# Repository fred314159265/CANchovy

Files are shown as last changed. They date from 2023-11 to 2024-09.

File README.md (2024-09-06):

# CANchovy USB-CAN Interface

This repository contains the design file for an isolated USB-CAN interface PCB. It is based upon the MKS CANable V2.0 and is compatible with the [CANable V2.0 firmware](https://github.com/normaldotcom/canable2-fw). It connects to the CAN bus via RJ45 connectors which can be configured with whatever pinout you require!

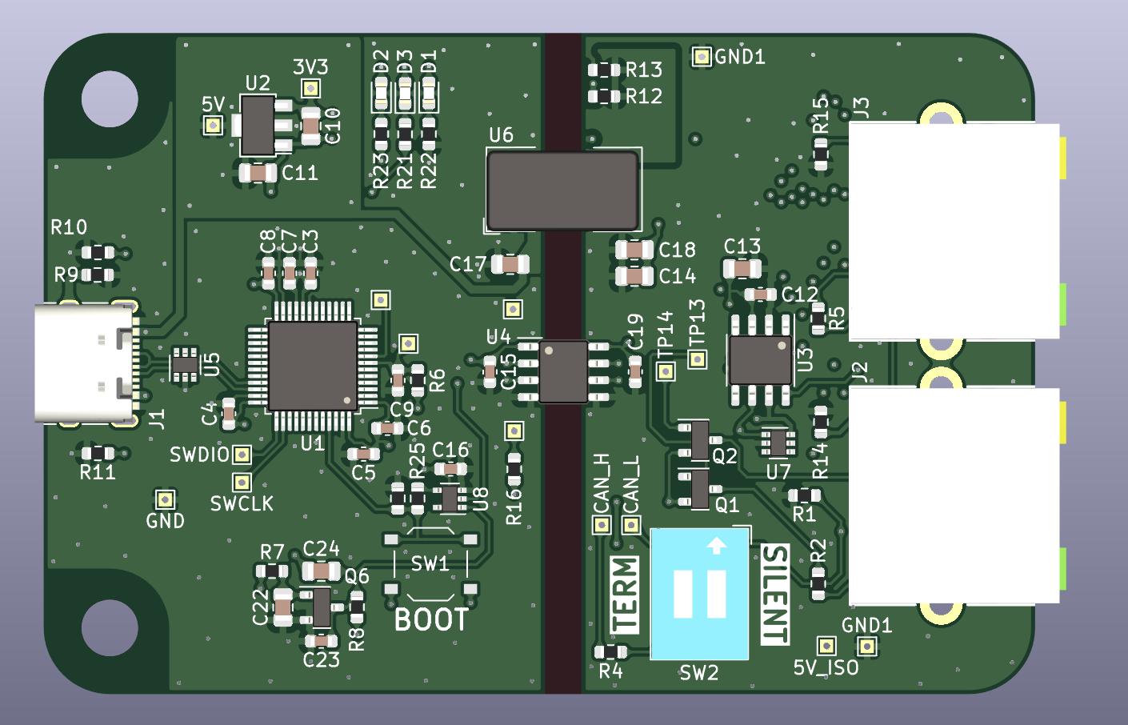
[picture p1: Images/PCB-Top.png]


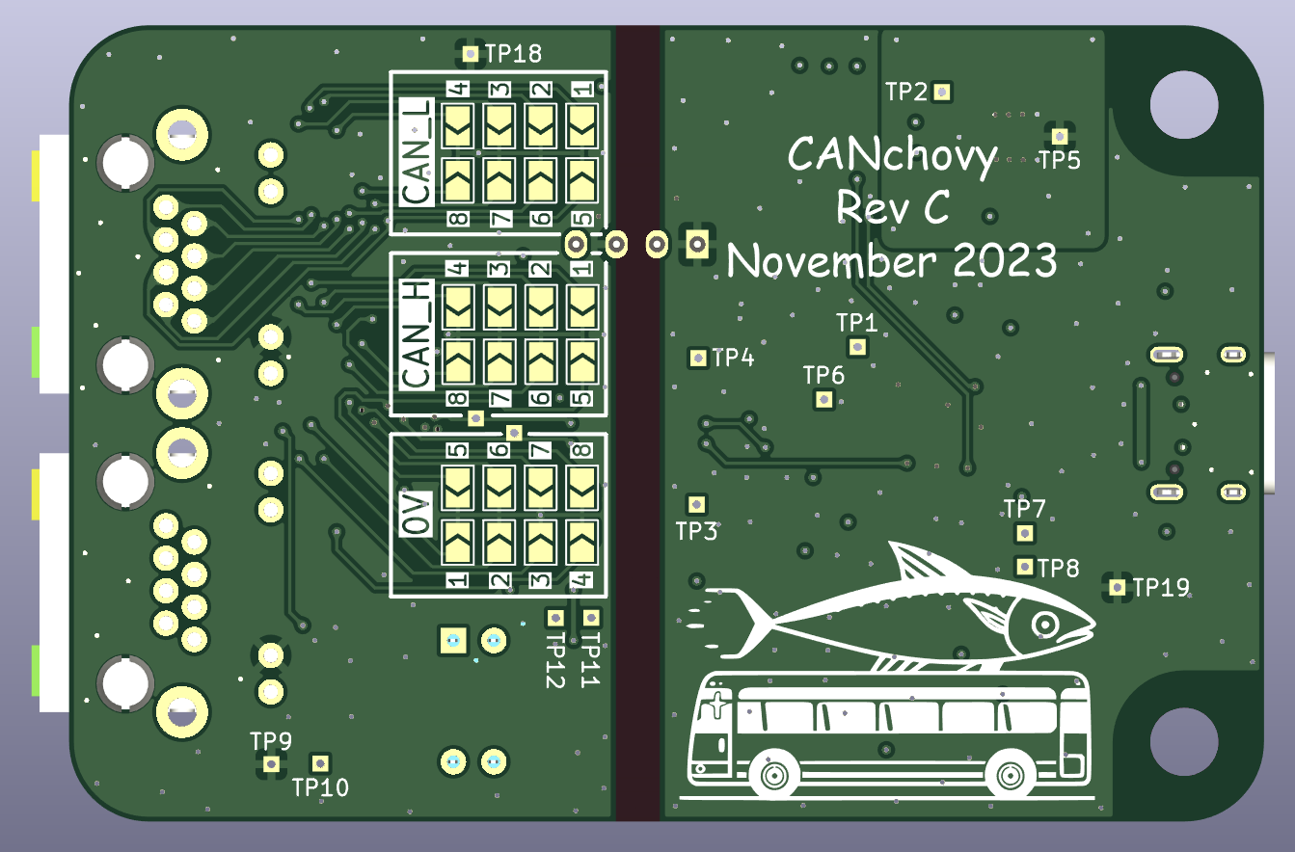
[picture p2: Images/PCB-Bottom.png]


## Features

* Firmware compatible with [CANable V2.0 firmware](https://github.com/normaldotcom/canable2-fw) - can be flashed & updated with the [CANable 2.0 web updater](https://canable.io/updater/canable2.html).
* RJ45 pinout configured via solder-able jumpers.
* Galvanic isolation between CAN port and USB.
* Two RJ45 connector in parallel allows for inserting inline on bus - all eight signal are passed through.
* DIP switch to enable or disable CAN termination.
* DIP switch to enable silent mode, preventing the CANchovy from transmitting on the bus in hardware.
* JLCPCB basic parts used where possible and all parts available for JLCPCB assembly service. Five CANchovies fully assembled with postage costs around $20 per CANchovy.
* 3D printed case design files.

# Status

Assembled CANchovies from JLCPCB of both revision A & B have been tested and work correctly. The only issues with these version were silkscreen issues.

Revision C has the silkscreen fixed and is ready to manufacture and use.

# Firmware

As the CANchovy is based upon the MKS CANable V2.0, it is compatible with firmware which is compatible with the MKS CANable V2.0.

There area couple of suitable firmware options - which firmware you will want to use really depends on your use case. 

## gs_usb

Using a firmware version which uses the gs_usb protocol will mostly be useful for SocketCAN on Linux, but [python-can](https://python-can.readthedocs.io/en/stable/interfaces/gs_usb.html) does support the gs_usb protocol on all platforms. (__Note:__ The Linux kernel only supports CAN FD with the gs_usb driver after version 5.18.)

* budgetcan_fw - [board_canablev2](https://github.com/ryedwards/budgetcan_fw/tree/main/Portable/board_canablev2) target - I have confirmed that FD CAN is working as of [`e8fb8efebdac22019dc7e73dfec773c6fd2ec5a8`](https://github.com/ryedwards/budgetcan-fw/commit/e8fb8efebdac22019dc7e73dfec773c6fd2ec5a8).
* candlelight build from [CANable 2.0 web updater](https://canable.io/updater/canable2.html) - I have not tested if FD CAN support is present, notes on canable website suggest FD support is not implemented in these candlelight FW builds (yet?).

## SLCAN

SLCAN is a protocol which operates over a serial port. Nearly all OS's have support for serial ports and so is very cross-platform. However, support for SLCAN is not very widespread.

You can also mount the serial port as a SocketCAN port on Linux (E.g. as described [here](https://elinux.org/Bringing_CAN_interface_up).), however, it does not support FD CAN at this time.

FD CAN is possible with the SLCAN firmware, but even fewer programs support FD with SLCAN (if any?). It may be a viable for custom applications where non-Linux is a requirement and Python is not an option.

* slcan with FD support build from [CANable 2.0 web updater](https://canable.io/updater/canable2.html) - [source repo](https://github.com/normaldotcom/canable2-fw).

# Configuring RJ45 Connections

As mentioned above, a feature of this board is that the RJ45's pinout is user configurable. By soldering one jumper for each of the three connections (0V, CAN_H, CAN_L) on the rear of the board, your custom CAN pinout over RJ45 can be supported!

Simply bridge one of the solder jumpers in each of the silkscreen boxes (labelled: 0V, CAN_H & CAN_L) to connect each signal to the corresponding pin number of the RJ45 connectors.

__⚠⚠⚠ Care must be taken to ensure no two signals are connected to the same RJ45 pin! ⚠⚠⚠__

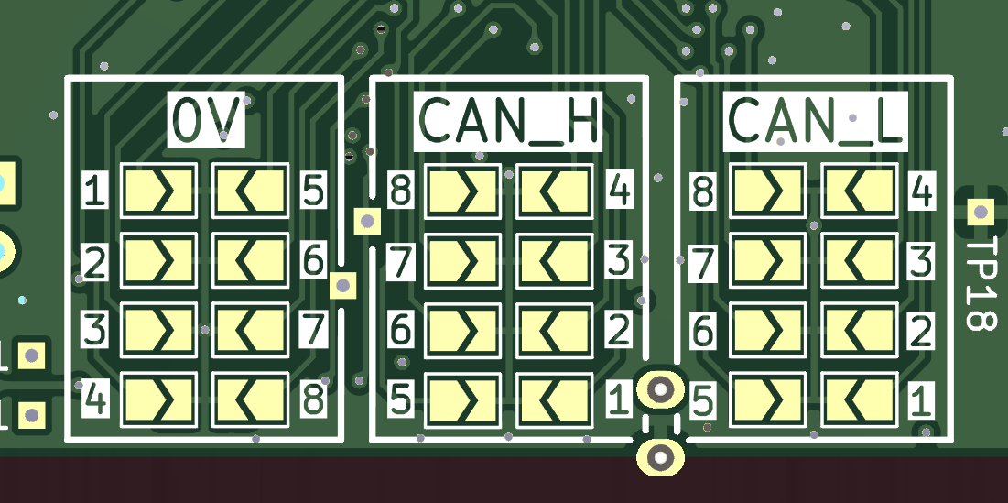
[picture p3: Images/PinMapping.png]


# Ordering

Gerbers, BOM, etc. can all be found in the [releases](https://github.com/fred314159265/CANchovy/releases) area.

When ordering from JLCPCB, is is suggested to select "JLC04161H-7628" under the controlled impedance option, although the USB run is so short that even non-controlled impedance stack-ups will likely work too.

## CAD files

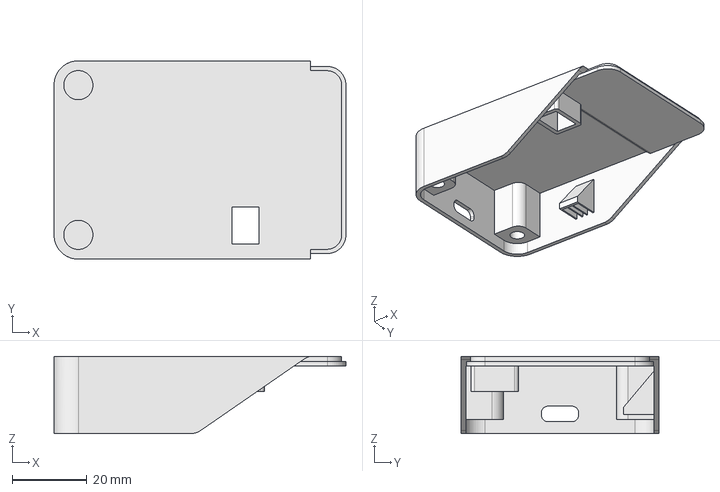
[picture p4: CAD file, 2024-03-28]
MCAD/CANchovy_Case-PartsCase_Top.step
78.0 x 53.0 x 20.6 mm

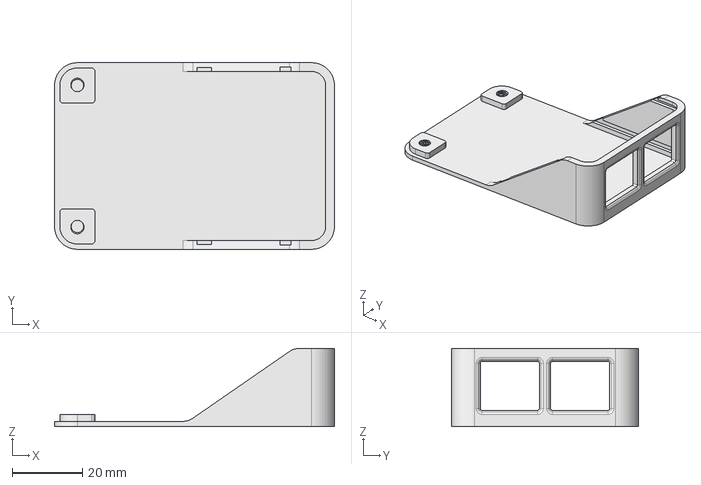
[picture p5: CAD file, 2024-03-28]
MCAD/CANchovy_Case-PartsCase_Base.step
79.5 x 53.0 x 22.2 mm

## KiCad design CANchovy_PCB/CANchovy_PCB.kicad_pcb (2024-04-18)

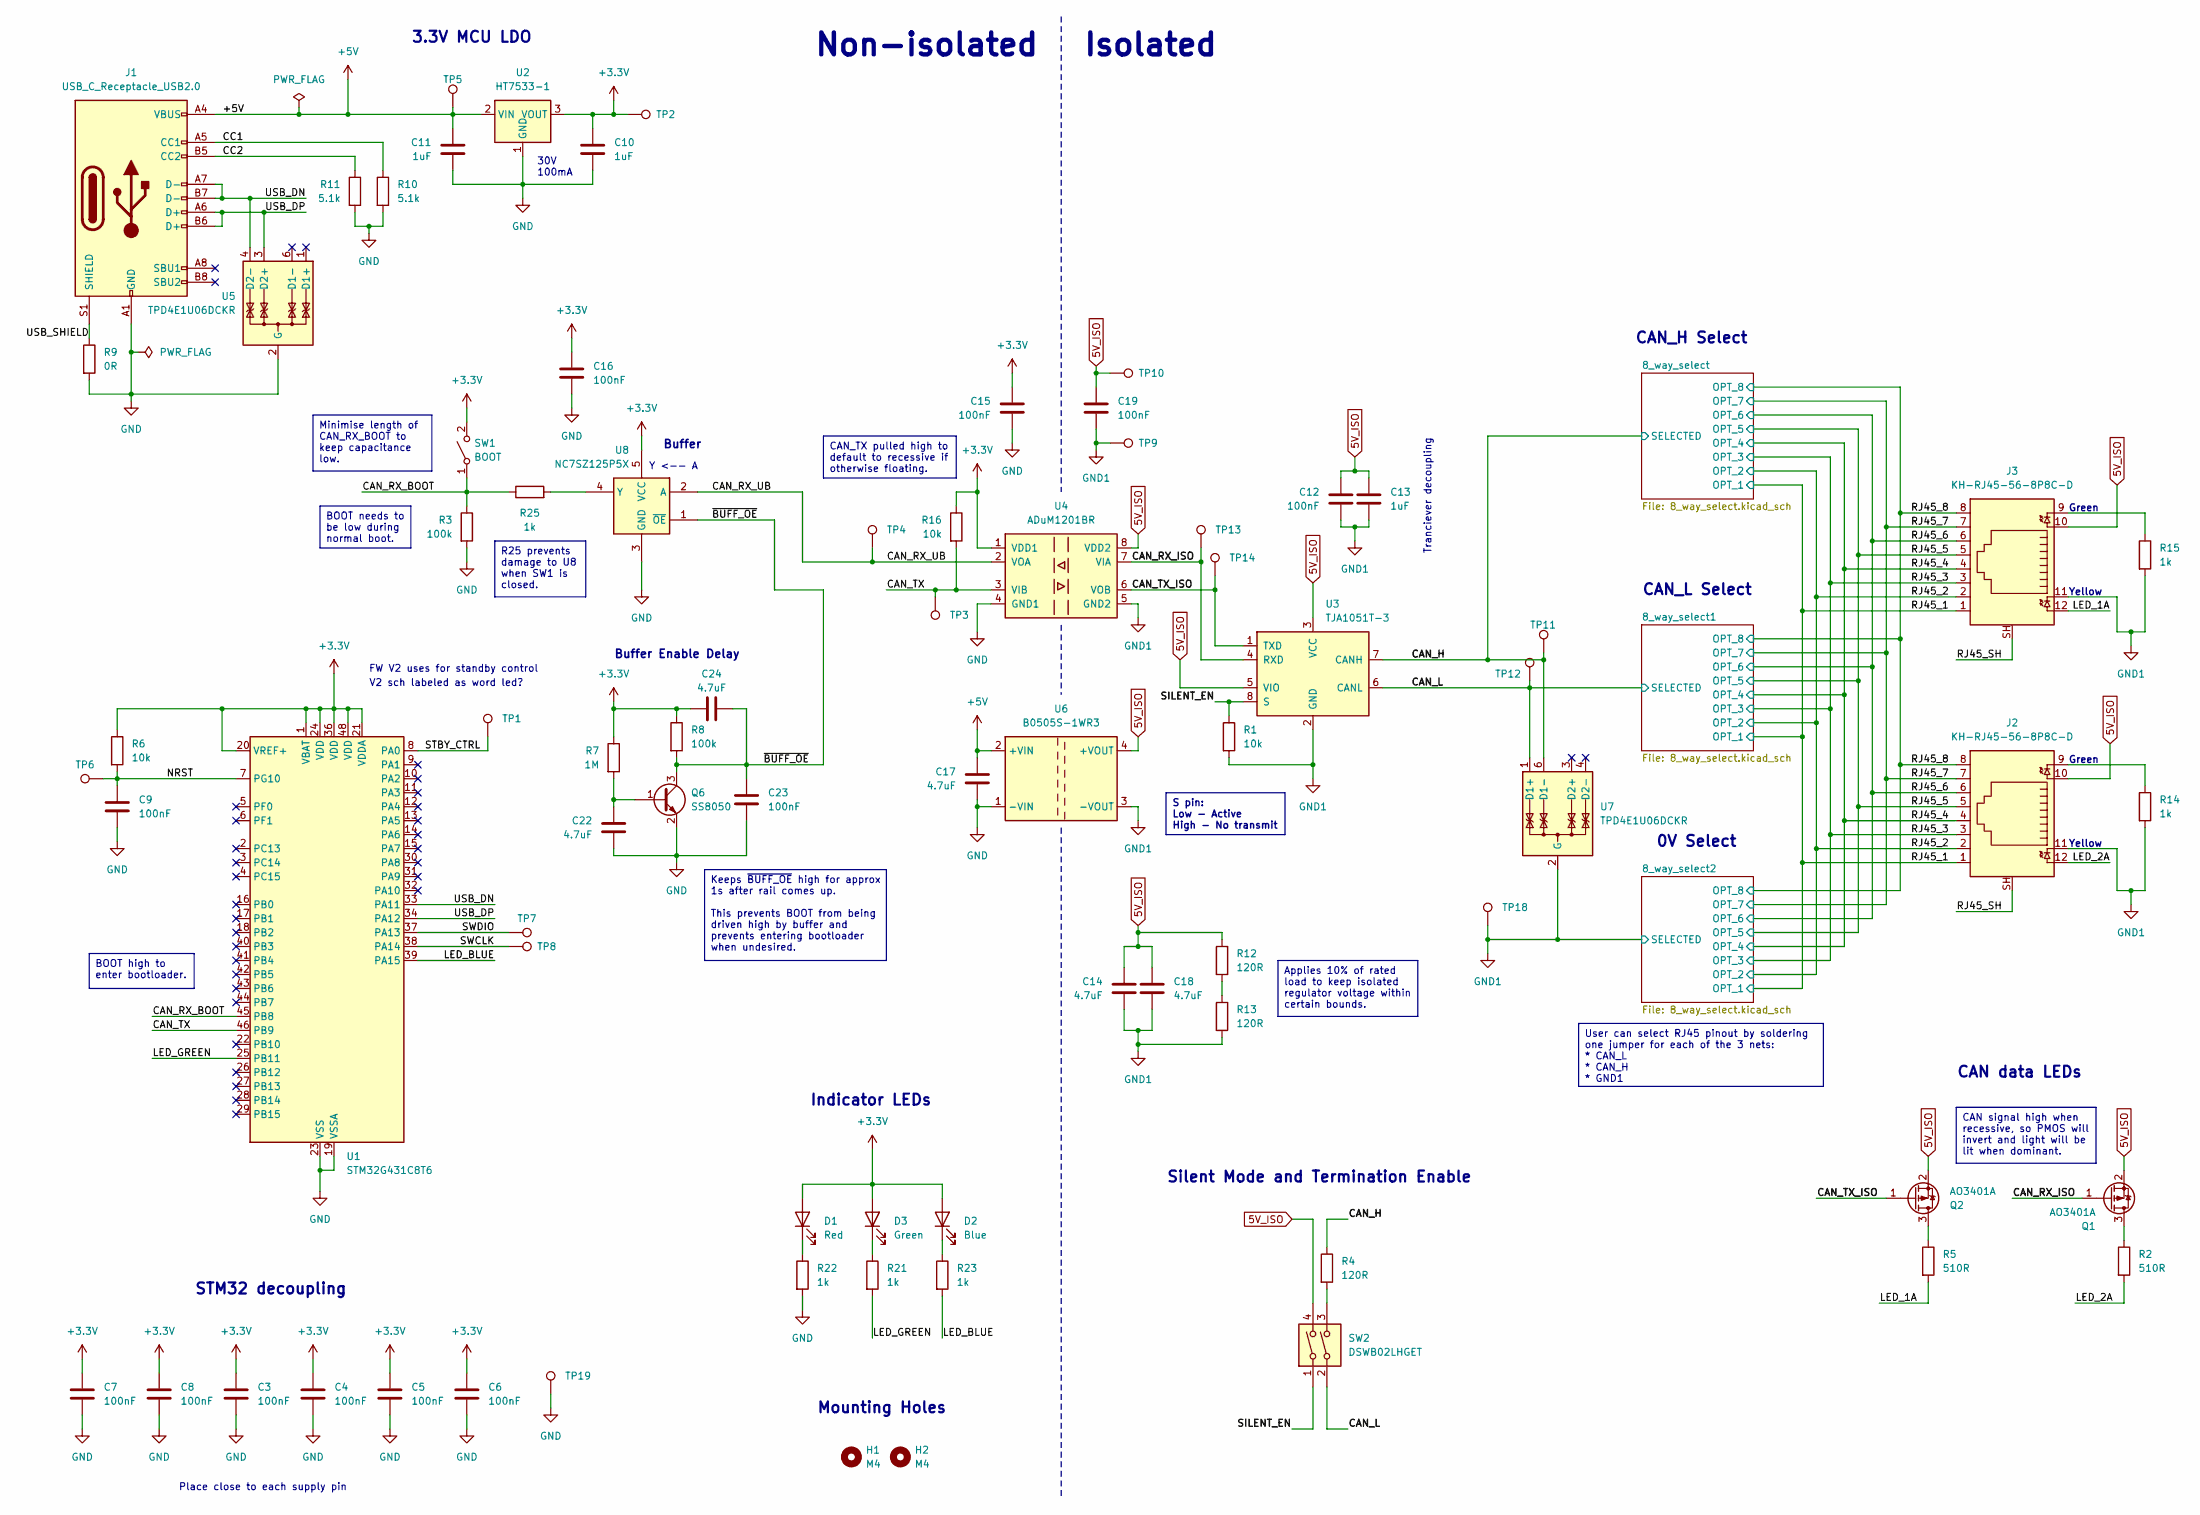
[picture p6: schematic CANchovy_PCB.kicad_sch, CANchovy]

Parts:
C3, C4, C5, C6, C7, C8, C9, C12, C15, C16, C19, C23: 100nF; C_0603_1608Metric; Manufacturer Part # CC0603KRX7R9BB104; LCSC Part # C14663
C10, C11, C13: 1uF; C_0805_2012Metric; Manufacturer Part # CL21B105KBFNNNE; LCSC Part # C28323
C14, C17, C18, C22, C24: 4.7uF; C_0805_2012Metric; Manufacturer Part # CL21A475KAQNNNE; LCSC Part # C1779
D1: Red; LED_0603_1608Metric; Manufacturer Part # KT-0603R; LCSC Part # C2286
D2: Blue; LED_0603_1608Metric; Manufacturer Part # XL-1608UBC-04; LCSC Part # C965807
D3: Green; LED_0603_1608Metric; Manufacturer Part # XL-1608UGC-04; LCSC Part # C965804
H1, H2: M4; MountingHole_4.3mm_M4
J1: USB_C_Receptacle_USB2.0; USB_C_Receptacle_XKB_U262-16XN-4BVC11; Manufacturer Part # U262-161N-4BVC11; LCSC Part # C319148
J2, J3: KH-RJ45-56-8P8C-D; Manufacturer Part # KH-RJ45-56-8P8C-D; LCSC Part # C2828082
Q1, Q2: AO3401A; SOT-23; LCSC Part # C15127
Q6: SS8050; SOT-23; Manufacturer Part # SS8050; LCSC Part # C2150
R1, R6, R16: 10k; R_0603_1608Metric; Manufacturer Part # 0603WAF1002T5E; LCSC Part # C25804
R2, R5: 510R; R_0603_1608Metric; Manufacturer Part # 0603WAF5100T5E; LCSC Part # C23193
R3, R8: 100k; R_0603_1608Metric; Manufacturer Part # 0603WAF1003T5E; LCSC Part # C25803
R4, R12, R13: 120R; R_0603_1608Metric; Manufacturer Part # 0603WAF1200T5E; LCSC Part # C22787
R7: 1M; R_0603_1608Metric; Manufacturer Part # 0603WAF1004T5E; LCSC Part # C22935
R9: 0R; R_0603_1608Metric; Manufacturer Part # 0603WAF0000T5E; LCSC Part # C21189
R10, R11: 5.1k; R_0603_1608Metric; Manufacturer Part # 0603WAF5101T5E; LCSC Part # C23186
R14, R15, R21, R22, R23, R25: 1k; R_0603_1608Metric; Manufacturer Part # 0603WAF1001T5E; LCSC Part # C21190
SW1: BOOT; SW_Push_1P1T_XKB_TS-1187A; Manufacturer Part # TS-1187A-B-A-B; LCSC Part # C318884
SW2: DSWB02LHGET; SW_DIP_SPSTx02_Slide_9.78x7.26mm_W7.62mm_P2.54mm; Manufacturer Part # DSWB02LHGET; LCSC Part # C99421
TP1, TP2, TP3, TP4, TP5, TP6, TP7, TP8, TP9, TP10, TP11, TP12, TP13, TP14, TP18, TP19: TestPoint; TestPoint_THTPad_1.0x1.0mm_Drill0.5mm
U1: STM32G431C8T6; LQFP-48_7x7mm_P0.5mm; Manufacturer Part # STM32G431C8T6; LCSC Part # C730096
U2: HT7533-1; SOT-89-3; Manufacturer Part # HT7533-1; LCSC Part # C14289
U3: TJA1051T-3; SOIC-8_3.9x4.9mm_P1.27mm; Manufacturer Part # TJA1051T/3/1J; LCSC Part # C38695
U4: ADuM1201BR; SOIC-8_3.9x4.9mm_P1.27mm; Manufacturer Part # ADUM1201BRZ-RL7; LCSC Part # C87626
U5, U7: TPD4E1U06DCKR; SOT-363_SC-70-6; LCSC Part # C194628
U6: B0505S-1WR3; Converter_DCDC_Murata_CRE1xxxxxx3C_THT; Manufacturer Part # B0505S-1WR3; LCSC Part # C5183119
U8: NC7SZ125P5X; SOT-353_SC-70-5; Manufacturer Part # NC7SZ125P5X; LCSC Part # C112084

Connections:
5V_ISO: C12.1, C13.1, C14.1, C18.1, C19.1, J2.10, J3.10, Q1.2 (S), Q2.2 (S), R12.1, SW2.4, TP10.1, U3.3 (VCC), U3.5 (VIO), U4.8 (VDD2), U6.4 (+VOUT)
+3.3V: C3.1, C4.1, C5.1, C6.1, C7.1, C8.1, C10.1, C15.1, C16.1, C24.1, D1.2 (A), D2.2 (A), D3.2 (A), R6.1, R7.1, R8.1, R16.1, SW1.2 (B), TP2.1, U1.1 (VBAT), U1.20 (VREF+), U1.21 (VDDA), U1.24 (VDD), U1.36 (VDD), U1.48 (VDD), U2.3 (VOUT), U4.1 (VDD1), U8.5 (VCC)
+5V: C11.1, C17.1, J1.A4 (VBUS), J1.A9 (VBUS), J1.B4 (VBUS), J1.B9 (VBUS), TP5.1, U2.2 (VIN), U6.2 (+VIN)
/CAN_H: R4.1, TP11.1, U3.7 (CANH), U7.6 (D1-); also elsewhere on the board
/CAN_L: SW2.2, TP12.1, U3.6 (CANL), U7.1 (D1+); also elsewhere on the board
/CAN_RX_BOOT: R3.1, R25.1, SW1.1 (A), U1.45 (PB8)
/CAN_RX_ISO: Q1.1 (G), TP13.1, U3.4 (RXD), U4.7 (VIA)
/CAN_RX_UB: TP4.1, U4.2 (VOA), U8.2 (A)
/CAN_TX: R16.2, TP3.1, U1.46 (PB9), U4.3 (VIB)
/CAN_TX_ISO: Q2.1 (G), TP14.1, U3.1 (TXD), U4.6 (VOB)
/CC1: J1.A5 (CC1), R10.1
/CC2: J1.B5 (CC2), R11.1
/LED_1A: J3.12, R5.2
/LED_2A: J2.12, R2.2
/LED_BLUE: R23.2, U1.39 (PA15)
/LED_GREEN: R21.2, U1.25 (PB11)
/NRST: C9.1, R6.2, TP6.1, U1.7 (PG10)
/RJ45_1: J2.1, J3.1; also elsewhere on the board
/RJ45_2: J2.2, J3.2; also elsewhere on the board
/RJ45_3: J2.3, J3.3; also elsewhere on the board
/RJ45_4: J2.4, J3.4; also elsewhere on the board
/RJ45_5: J2.5, J3.5; also elsewhere on the board
/RJ45_6: J2.6, J3.6; also elsewhere on the board
/RJ45_7: J2.7, J3.7; also elsewhere on the board
/RJ45_8: J2.8, J3.8; also elsewhere on the board
/RJ45_SH: J2.SH, J3.SH
/SILENT_EN: R1.1, SW2.1, U3.8 (S)
/STBY_CTRL: TP1.1, U1.8 (PA0)
/SWCLK: TP8.1, U1.38 (PA14)
/SWDIO: TP7.1, U1.37 (PA13)
/USB_DN: J1.A7 (D-), J1.B7 (D-), U1.33 (PA11), U5.4 (D2-)
/USB_DP: J1.A6 (D+), J1.B6 (D+), U1.34 (PA12), U5.3 (D2+)
/USB_SHIELD: J1.S1 (SHIELD), R9.1
/~BUFF_OE: C23.1, C24.2, Q6.3 (C), R8.2, U8.1 (~OE)
GND: C3.2, C4.2, C5.2, C6.2, C7.2, C8.2, C9.2, C10.2, C11.2, C15.2, C16.2, C17.2, C22.1, C23.2, J1.A1 (GND), J1.A12 (GND), J1.B1 (GND), J1.B12 (GND), Q6.2 (E), R3.2, R9.2, R10.2, R11.2, R22.2, TP19.1, U1.19 (VSSA), U1.23 (VSS), U1.35 (VSS), U1.47 (VSS), U2.1 (GND), U4.4 (GND1), U5.2 (G), U6.1 (-VIN), U8.3 (GND)
GND1: C12.2, C13.2, C14.2, C18.2, C19.2, J2.11, J3.11, R1.2, R13.2, R14.2, R15.2, TP9.1, TP18.1, U3.2 (GND), U4.5 (GND2), U6.3 (-VOUT), U7.2 (G); also elsewhere on the board
unnamed: D1.1 (K), R22.1
unnamed: D2.1 (K), R23.1
unnamed: D3.1 (K), R21.1
unnamed: J2.9, R14.1
unnamed: J3.9, R15.1
unnamed: Q1.3 (D), R2.1
unnamed: Q2.3 (D), R5.1
unnamed: C22.2, Q6.1 (B), R7.2
unnamed: R4.2, SW2.3
unnamed: R12.2, R13.1
unnamed: R25.2, U8.4 (Y)

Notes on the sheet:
Applies 10% of rated load to keep isolated regulator voltage within certain bounds.
BOOT high to enter bootloader.
BOOT needs to be low during normal boot.
S pin: Low - Active High - No transmit
User can select RJ45 pinout by soldering one jumper for each of the 3 nets: * CAN_L * CAN_H * GND1
Keeps ~{BUFF_OE} high for approx 1s after rail comes up. This prevents BOOT from being driven high by buffer and prevents entering bootloader when undesired.
R25 prevents damage to U8 when SW1 is closed.
CAN signal high when recessive, so PMOS will invert and light will be lit when dominant.
CAN_TX pulled high to default to recessive if otherwise floating.
Minimise length of CAN_RX_BOOT to keep capacitance low.
Mounting Holes
STM32 decoupling
CAN_H Select
Green
Isolated
30V 100mA
Buffer
Y <-- A
Place close to each supply pin
Yellow
Silent Mode and Termination Enable
V2 sch labeled as word led?
Buffer Enable Delay
Non-isolated
3.3V MCU LDO
Tranciever decoupling
0V Select
CAN data LEDs
Indicator LEDs
CAN_L Select
FW V2 uses for standby control

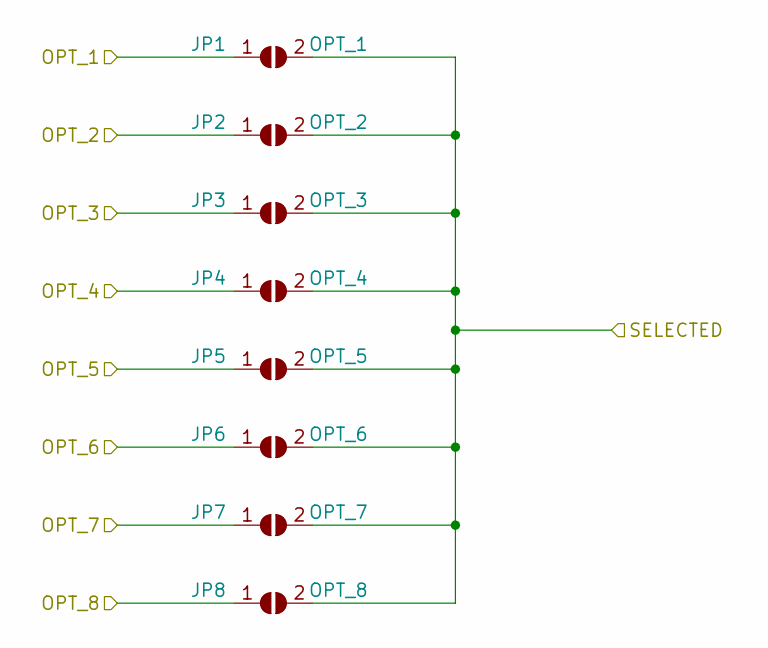
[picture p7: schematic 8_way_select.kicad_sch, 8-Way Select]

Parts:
JP1: OPT_1; SolderJumper-2_P1.3mm_Open_TrianglePad1.0x1.5mm
JP2: OPT_2; SolderJumper-2_P1.3mm_Open_TrianglePad1.0x1.5mm
JP3: OPT_3; SolderJumper-2_P1.3mm_Open_TrianglePad1.0x1.5mm
JP4: OPT_4; SolderJumper-2_P1.3mm_Open_TrianglePad1.0x1.5mm
JP5: OPT_5; SolderJumper-2_P1.3mm_Open_TrianglePad1.0x1.5mm
JP6: OPT_6; SolderJumper-2_P1.3mm_Open_TrianglePad1.0x1.5mm
JP7: OPT_7; SolderJumper-2_P1.3mm_Open_TrianglePad1.0x1.5mm
JP8: OPT_8; SolderJumper-2_P1.3mm_Open_TrianglePad1.0x1.5mm

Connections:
/CAN_H: JP1.2 (B), JP2.2 (B), JP3.2 (B), JP4.2 (B), JP5.2 (B), JP6.2 (B), JP7.2 (B), JP8.2 (B); also elsewhere on the board
/RJ45_1: JP1.1 (A); also elsewhere on the board
/RJ45_2: JP2.1 (A); also elsewhere on the board
/RJ45_3: JP3.1 (A); also elsewhere on the board
/RJ45_4: JP4.1 (A); also elsewhere on the board
/RJ45_5: JP5.1 (A); also elsewhere on the board
/RJ45_6: JP6.1 (A); also elsewhere on the board
/RJ45_7: JP7.1 (A); also elsewhere on the board
/RJ45_8: JP8.1 (A); also elsewhere on the board

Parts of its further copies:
JP9, JP17: OPT_1; SolderJumper-2_P1.3mm_Open_TrianglePad1.0x1.5mm
JP10, JP18: OPT_2; SolderJumper-2_P1.3mm_Open_TrianglePad1.0x1.5mm
JP11, JP19: OPT_3; SolderJumper-2_P1.3mm_Open_TrianglePad1.0x1.5mm
JP12, JP20: OPT_4; SolderJumper-2_P1.3mm_Open_TrianglePad1.0x1.5mm
JP13, JP21: OPT_5; SolderJumper-2_P1.3mm_Open_TrianglePad1.0x1.5mm
JP14, JP22: OPT_6; SolderJumper-2_P1.3mm_Open_TrianglePad1.0x1.5mm
JP15, JP23: OPT_7; SolderJumper-2_P1.3mm_Open_TrianglePad1.0x1.5mm
JP16, JP24: OPT_8; SolderJumper-2_P1.3mm_Open_TrianglePad1.0x1.5mm

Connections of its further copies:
/CAN_L: JP9.2 (B), JP10.2 (B), JP11.2 (B), JP12.2 (B), JP13.2 (B), JP14.2 (B), JP15.2 (B), JP16.2 (B); also elsewhere on the board
/RJ45_1: JP9.1 (A), JP17.1 (A); also elsewhere on the board
/RJ45_2: JP10.1 (A), JP18.1 (A); also elsewhere on the board
/RJ45_3: JP11.1 (A), JP19.1 (A); also elsewhere on the board
/RJ45_4: JP12.1 (A), JP20.1 (A); also elsewhere on the board
/RJ45_5: JP13.1 (A), JP21.1 (A); also elsewhere on the board
/RJ45_6: JP14.1 (A), JP22.1 (A); also elsewhere on the board
/RJ45_7: JP15.1 (A), JP23.1 (A); also elsewhere on the board
/RJ45_8: JP16.1 (A), JP24.1 (A); also elsewhere on the board
GND1: JP17.2 (B), JP18.2 (B), JP19.2 (B), JP20.2 (B), JP21.2 (B), JP22.2 (B), JP23.2 (B), JP24.2 (B); also elsewhere on the board

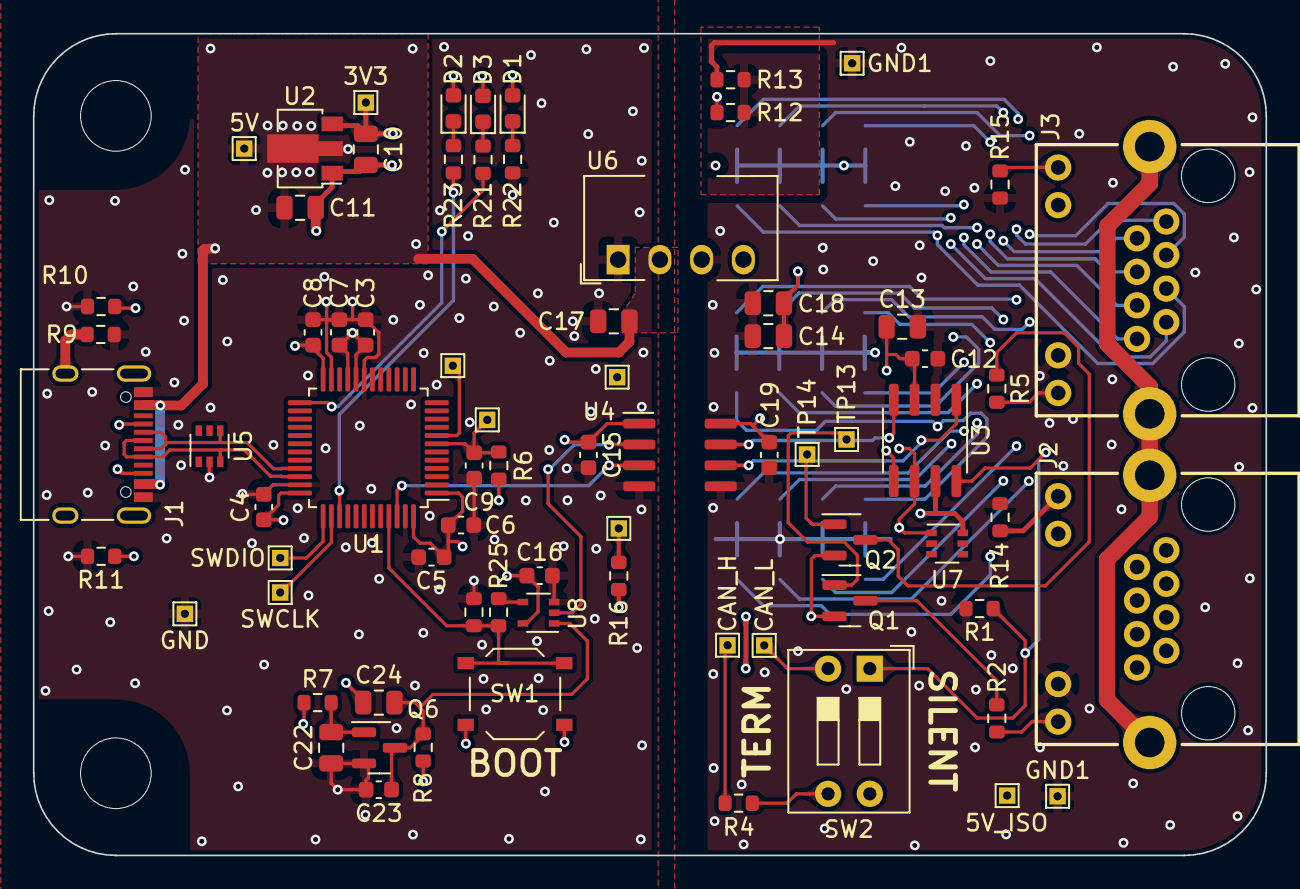
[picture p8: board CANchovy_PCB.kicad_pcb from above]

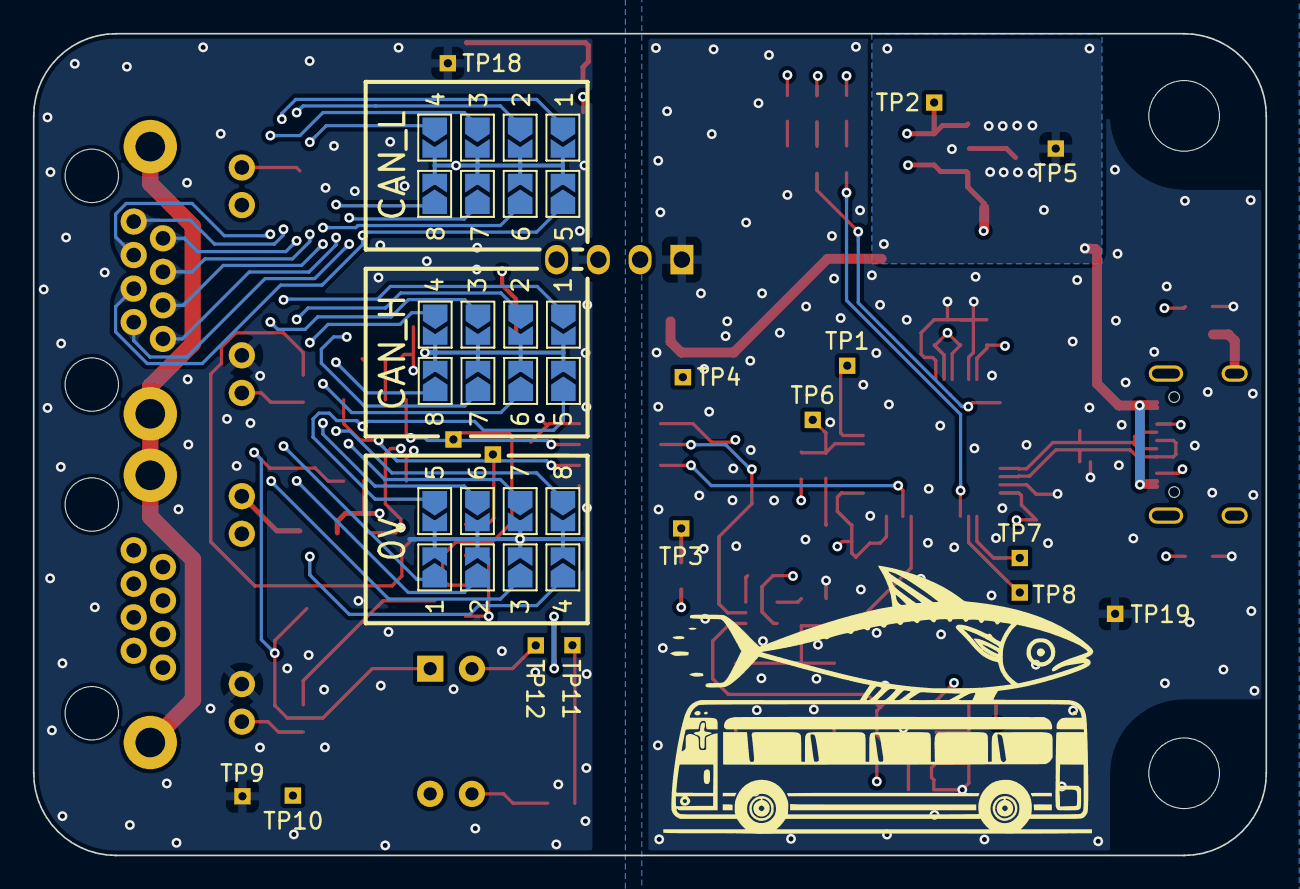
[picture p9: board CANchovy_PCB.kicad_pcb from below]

Board: 4 copper layers, 75.0 x 50.0 mm, 101 parts (24 on the bottom side), 47 nets.

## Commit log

2023-10-07 Schematics starting to take shape.
    [8_way_select.kicad_sch, CANable_ISO_PCB.kicad_pcb, CANable_ISO_PCB.kicad_sch]
2023-10-13 Schematic pretty much done.
    Could do with a tidy though...
    [CANable_ISO_PCB.kicad_pcb, CANable_ISO_PCB.kicad_sch]
2023-10-16 Isolated side of layout in progress.
    [CANable_ISO_PCB.kicad_pcb, CANable_ISO_PCB.kicad_sch]
2023-10-23 Layout complete for now.
    [CANable_ISO_PCB.kicad_pcb]
2023-10-31 CANchovy Rev A release.
    [8_way_select.kicad_sch, CANable_ISO_PCB.kicad_pcb, CANable_ISO_PCB.kicad_sch]
2023-11-14 First go at case WIP
2023-11-15 Corrected RJ45 footprint pinout and updated PCB to correctly label solder jumpers.
    [8_way_select.kicad_sch, CANable_ISO_PCB.kicad_pcb]
2023-11-15 Renamed KiCAD things to "CANchovy_PCB".
    [8_way_select.kicad_sch, CANable_ISO_PCB.kicad_pcb, CANable_ISO_PCB.kicad_sch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]
2023-11-16 Revision B release.
    Changes:
    - Silkscreen numbering corrected for RJ45 numberings.
    - RJ45 LEDs for RX/TX now ~twice the current.
    [8_way_select.kicad_sch, CANchovy_PCB.kicad_pcb, CANchovy_PCB.kicad_sch]
2023-11-16 Making some progress on 3DP case.
2023-11-19 MVP 3DP case complete.
    [CANchovy_Case-PartsCase_Base.step, CANchovy_Case-PartsCase_Top.step]
2023-11-30 Revision C & readme updates.
    [8_way_select.kicad_sch, CANchovy_PCB.kicad_pcb, CANchovy_PCB.kicad_sch]
2024-04-18 Release V1.0
    Green LED D3 changed to C965804.
    Blue LED D2 changed to C965807.
    README edits.
    Design files updated to KiCAD V8 format.
    [8_way_select.kicad_sch, CANchovy_PCB.kicad_pcb, CANchovy_PCB.kicad_sch]
